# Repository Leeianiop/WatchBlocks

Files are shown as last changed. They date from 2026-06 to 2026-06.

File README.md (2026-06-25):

# WatchBlocks
The New Fashion is Customizable  
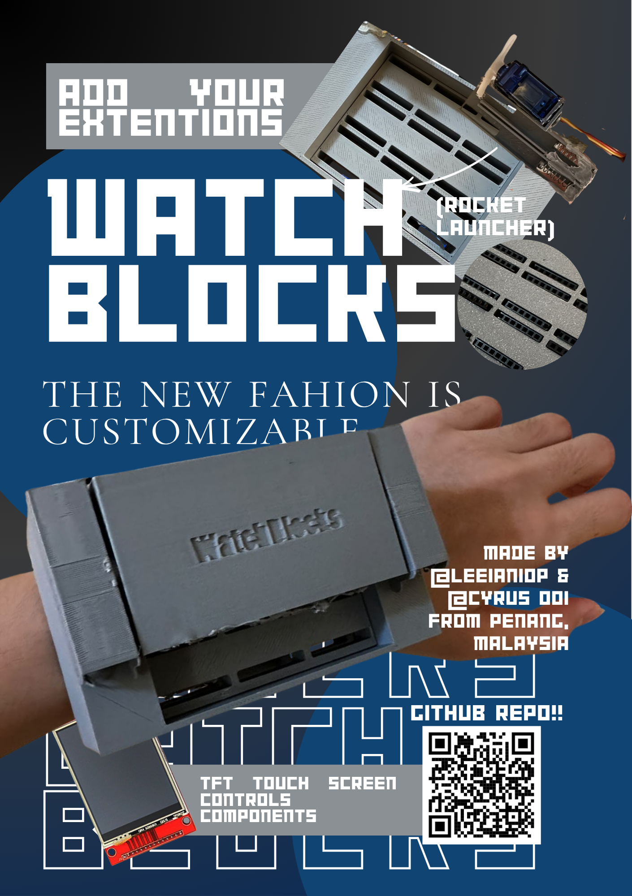
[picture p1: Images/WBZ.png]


## Inspired by the legendary "PhoneBlocks"  
A watch that can be added on extensions.

## How it started
This idea came to me when I saw the story of the PhoneBlocks Movement and how it eventually died out. I suppose an issue was also that nobody was willing to risk having their phones being blocks., and rather go with traditional "Big Brands"  
So, I lowered it down into a compact watch, well its more of a wrist bracelet thingymabob if you think about it. (WatchBlocks sounds cooler than Wrist-Bracelet-ThingymabobBlocks)  

## BOM
# WatchBlocks - Bill of Materials (BOM)

## Core Components

| Component | Description | Qty | Cost |
|---|---|---|---|
| ESP32S3 XIAO | Microcontroller | 1 | $13.73 |
| 1.8" TFT Touch Screen Display | UI Display | 1 | $2.57 |
| Perfboard Wires | Connect the circuit | 1 | $1.48 |
| Female Pin Header (1x40) | Solder to PCB | 1 | $0.20 |
| Male Pin Header (1x40) | Connect extensions to socket | 6 | $0.72 |
| Magnets (10 pcs) | Locking extensions and closures | 1 | $1.20 |
| DS3231 RTC Module | Track local time offline | 1 | $2.21 |

## Power System

| Component | Description | Qty | Cost |
|---|---|---|---|
| Lipo Battery 3.7v | Supply power | 1 | $1.03 |
| Velcro Strap | Wrist strap | 1 | $3.01 |
| Velcro Patch | Attach block to strap | 1 | $1.15 |

## Speaker Extension

| Component | Description | Qty | Cost |
|---|---|---|---|
| 4Ω Speaker | Audio output | 1 | $3.63 |

## Rocket Launcher 3000 Extension

| Component | Description | Qty | Cost |
|---|---|---|---|
| Servo Motor | Launch mechanism | 1 | $1.54 |
| Springs | Hold and launch rockets | 1 | $0.76 |

## PCB 4 layers

| Component | Description | Qty | Cost |
|---|---|---|---|
| Top PCB | Get Quote on JLCPCB | 1 | $7 |
| Bottom PCB | Get Quote on JLCPCB | 1 | $7 |

# Total Cost

**$47.23**

## Files
STL files include an extentions folder which are for the speaker extention and rocket launcher extentions.     
If you want to make your own extention which you definetly should (its the whole purpose of this project) modify (WatchBlocksTemplate)    
PCB file has 2 pcb inside for the top (left) and bottom layer (right).  PCB also has 4 layers, below are all of them separately   
PCB "+" Sign also indicates the way you should place the PCB, so make sure bot "+" of your PCB are facing the same direction
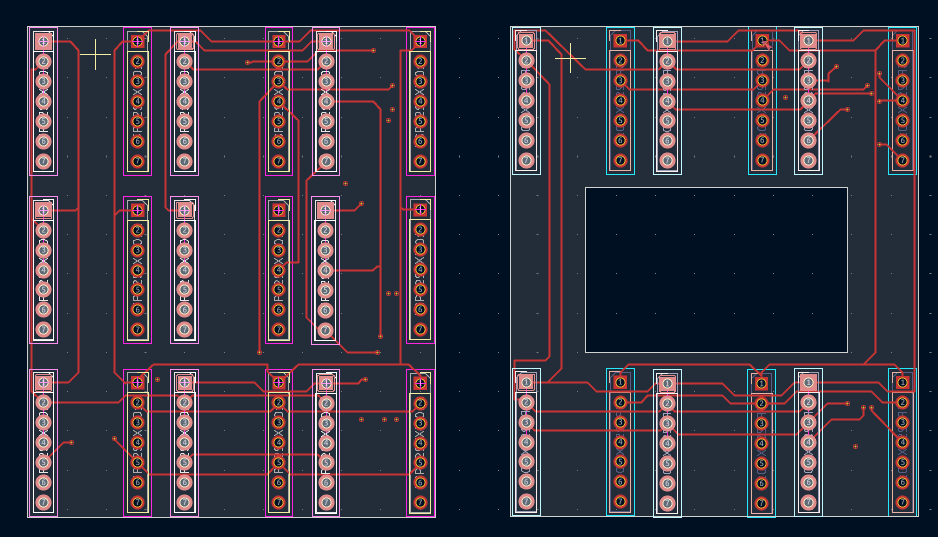
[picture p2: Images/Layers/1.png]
  
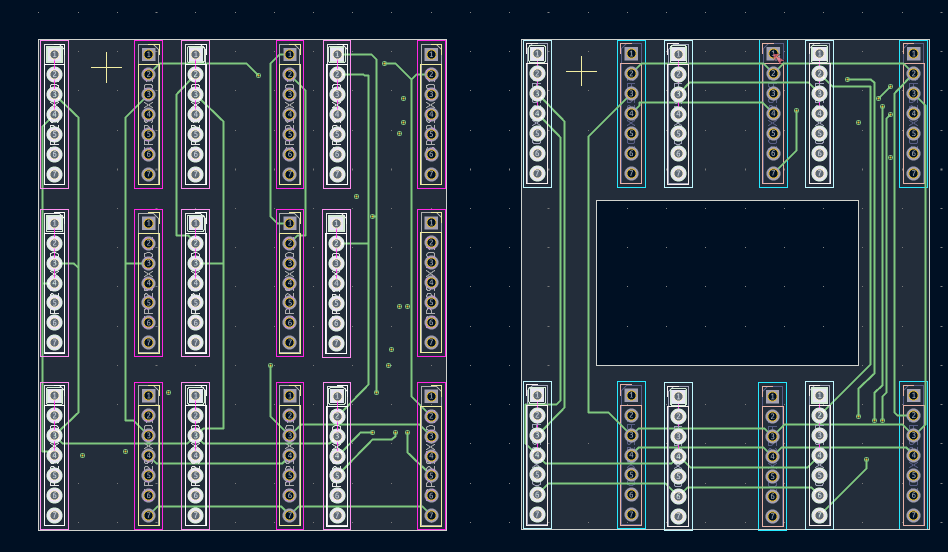
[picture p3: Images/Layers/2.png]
  
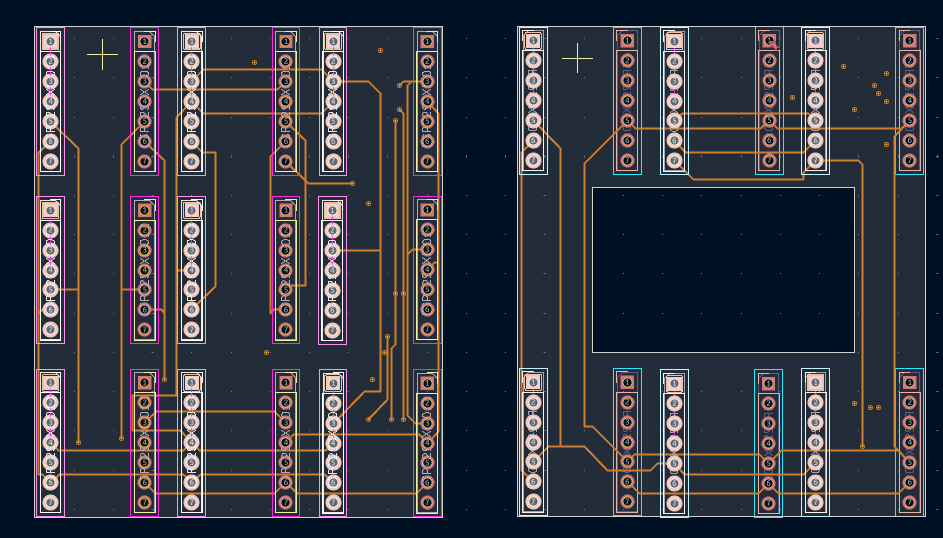
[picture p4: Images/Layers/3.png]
  
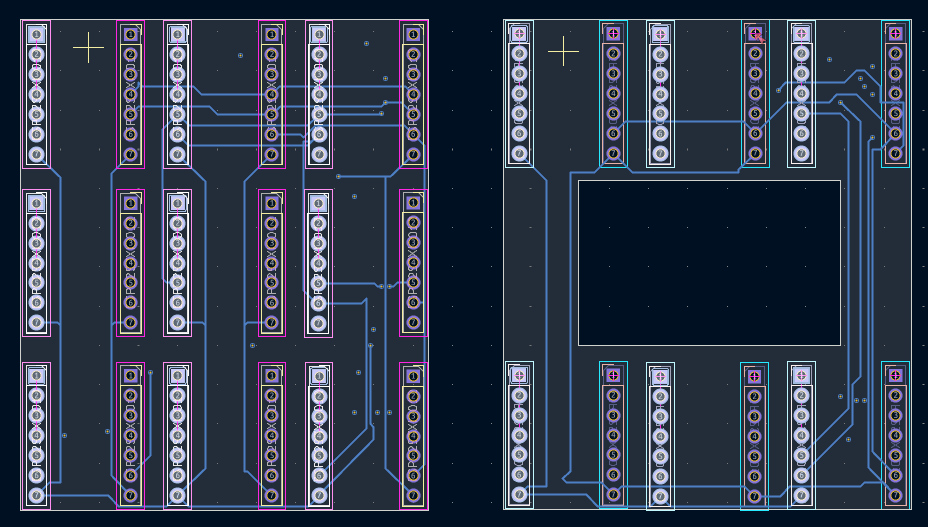
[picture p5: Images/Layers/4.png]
   
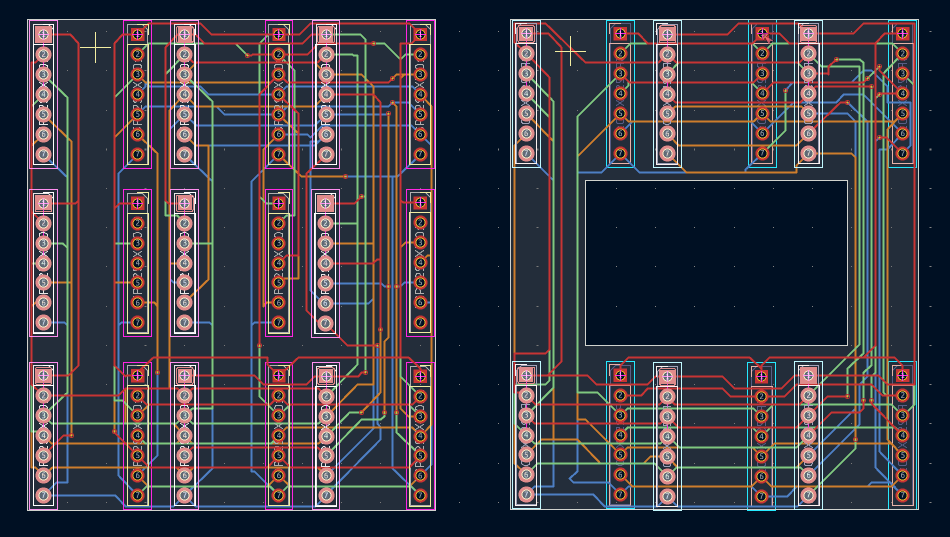
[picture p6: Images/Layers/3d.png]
  
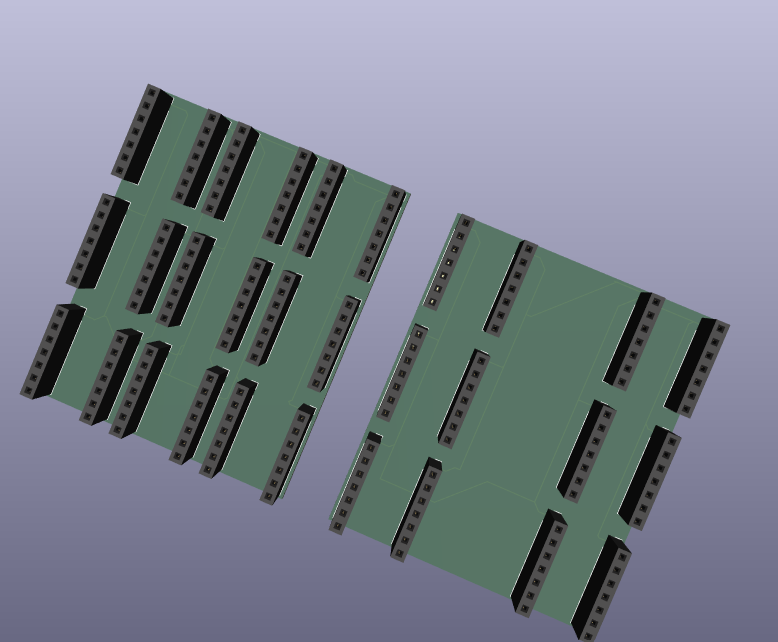
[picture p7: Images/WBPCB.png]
  
## Where everything goes  
### 1. Start by soldering the wires then sliding in the tft.  
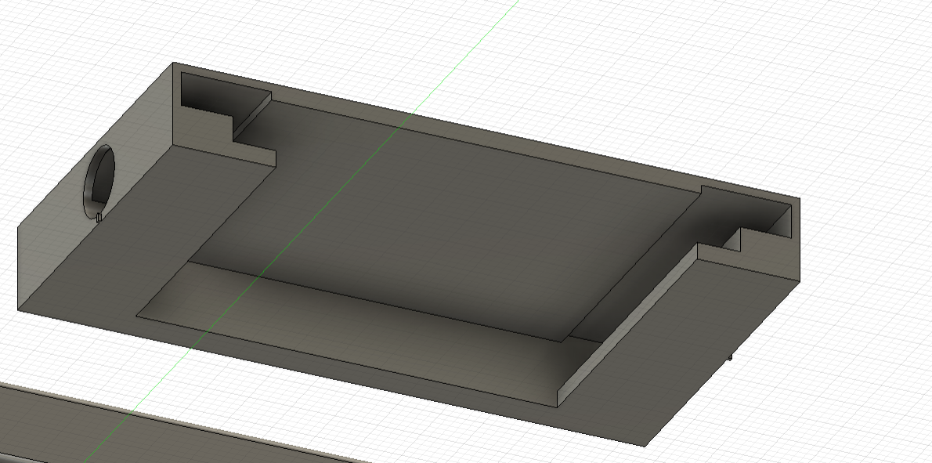
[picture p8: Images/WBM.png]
  
### 2. Close the lid & fit both the sliders in, remember to fit the wires of the tft through the hole and into the main case.
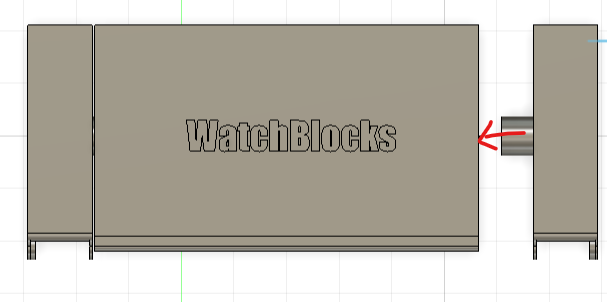
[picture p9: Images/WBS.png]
  
### 3. Align with Main Case and Hot glue them with the nuts and screws  
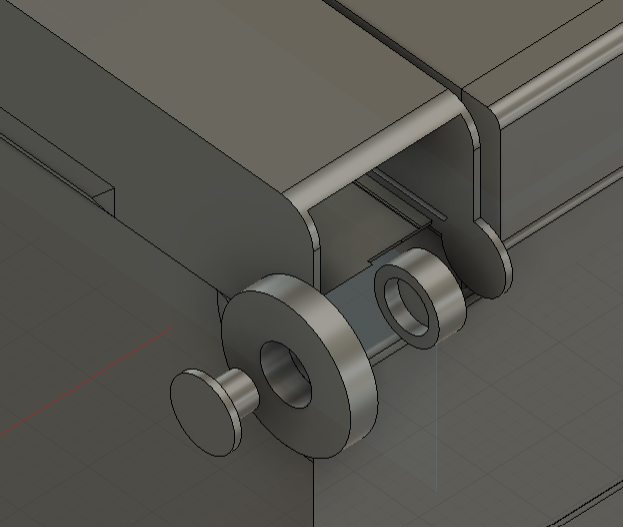
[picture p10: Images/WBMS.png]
  
### 4. IMPORTANT!! solder bottom pcb first (the one with 12 pin headers) Place xiao in (bottom to top), then use perfboard wire to connect them with XIAO, only then insert PCB in  
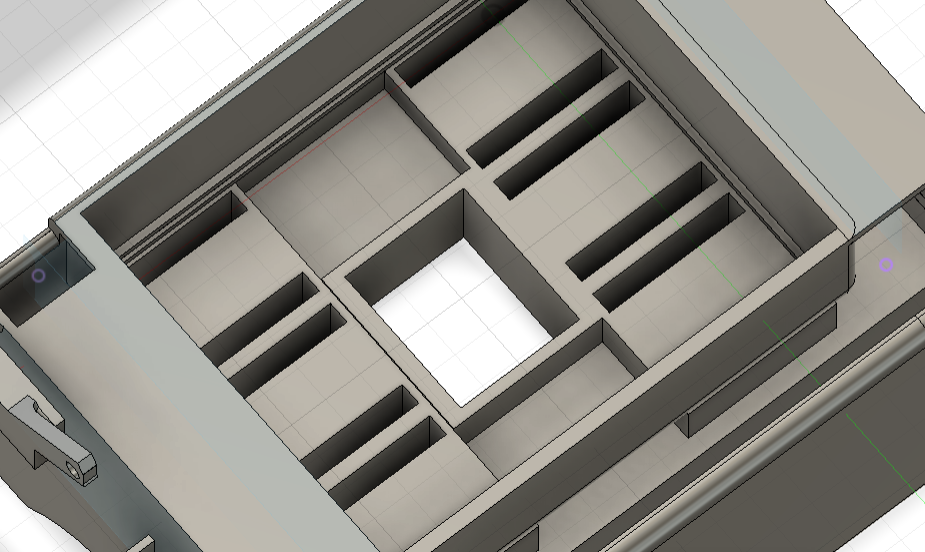
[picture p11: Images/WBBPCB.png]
  
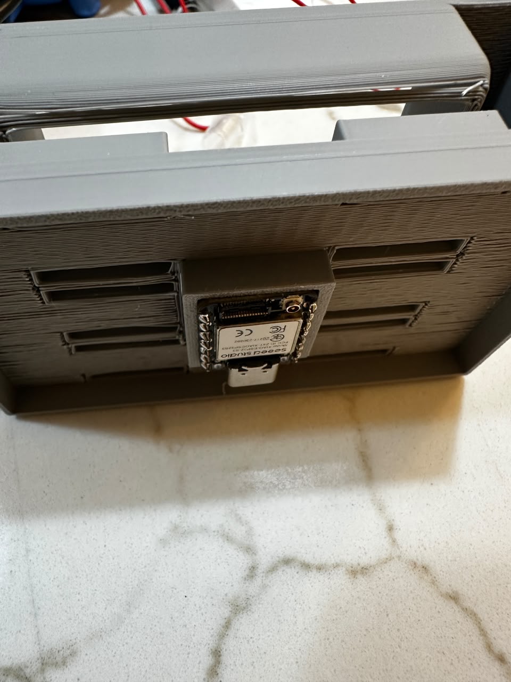
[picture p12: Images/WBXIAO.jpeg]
  
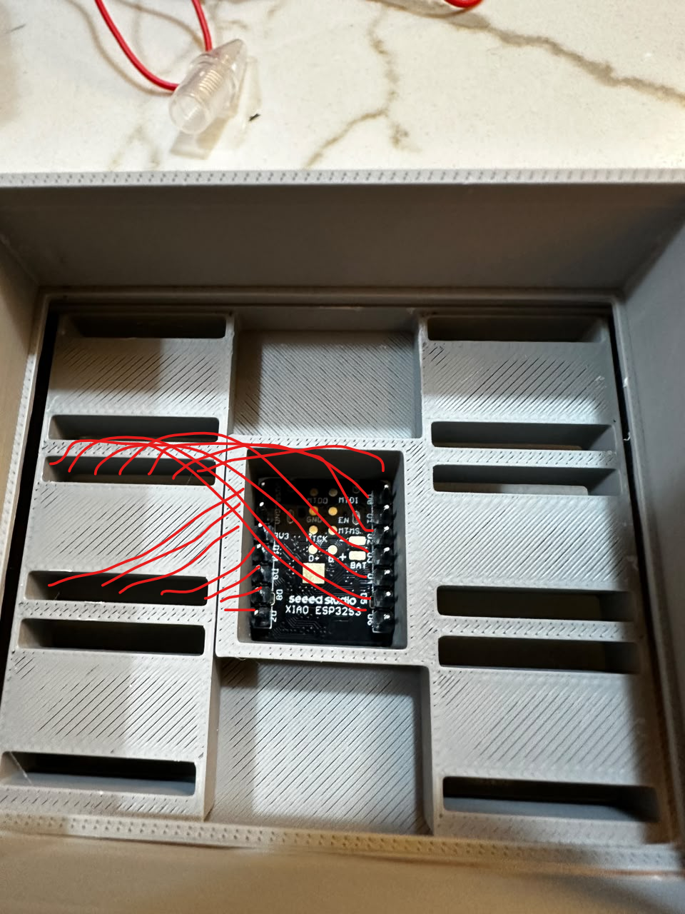
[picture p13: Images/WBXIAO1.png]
  
### 5. Now solder the to pcb with the XIAO and place it in, then put on the cover (WatchBlocksSocket)  
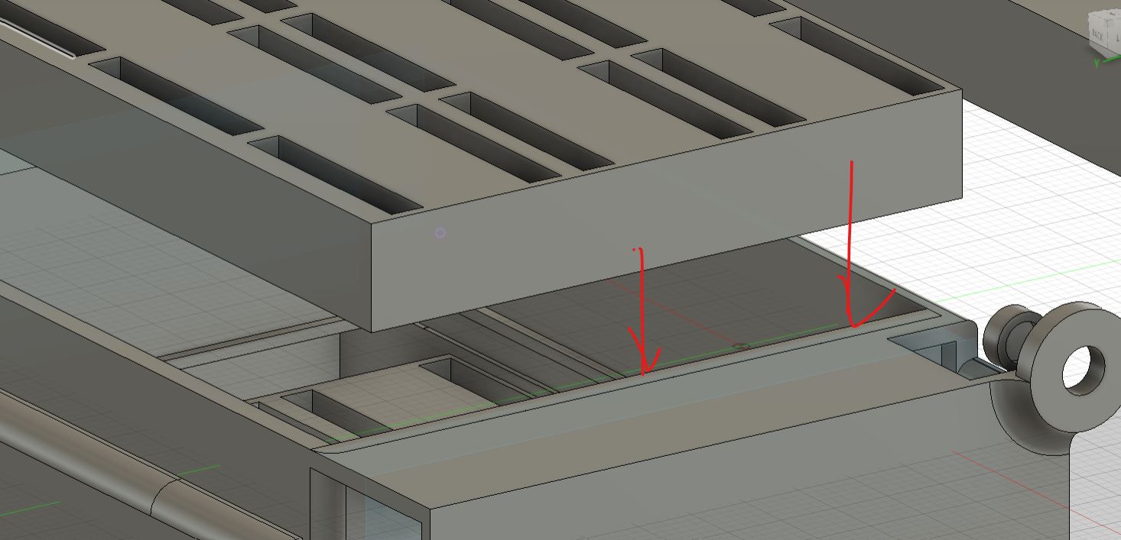
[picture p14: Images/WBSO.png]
   
### 6. Place Lipo battery in this cover, then connect with VBUS and GND to the pin headers
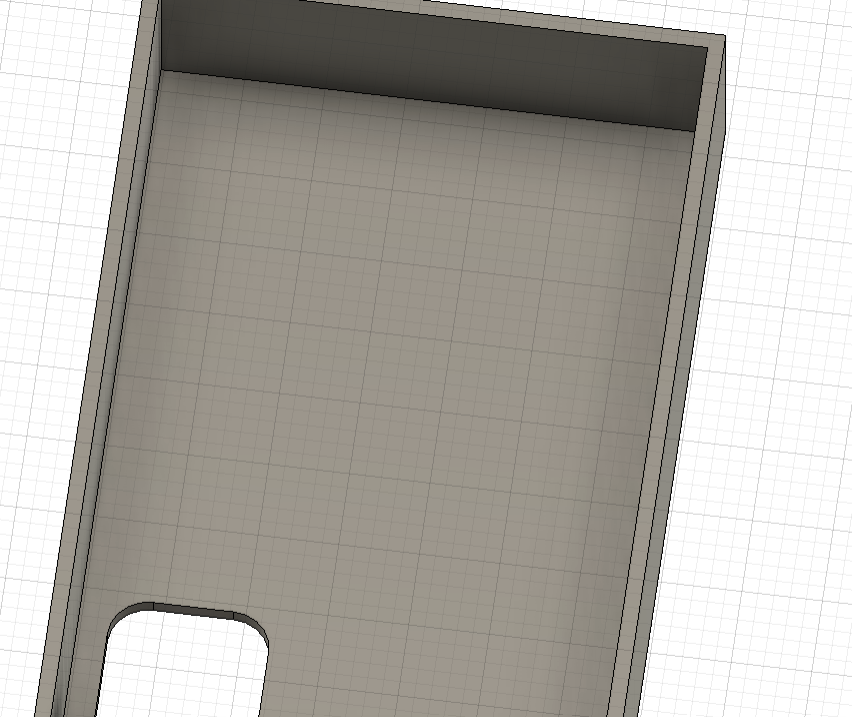
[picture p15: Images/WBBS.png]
  
### 7. Fit your RTC module in here and connect directly to the XIAO sharing the same I2C bus  
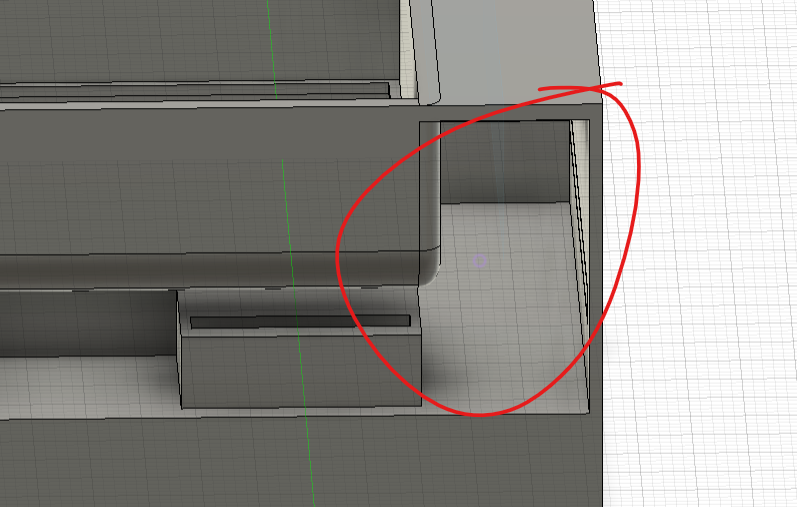
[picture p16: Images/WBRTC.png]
  
### 8. Close the MAIN Lid, and that's it, really simple !!  
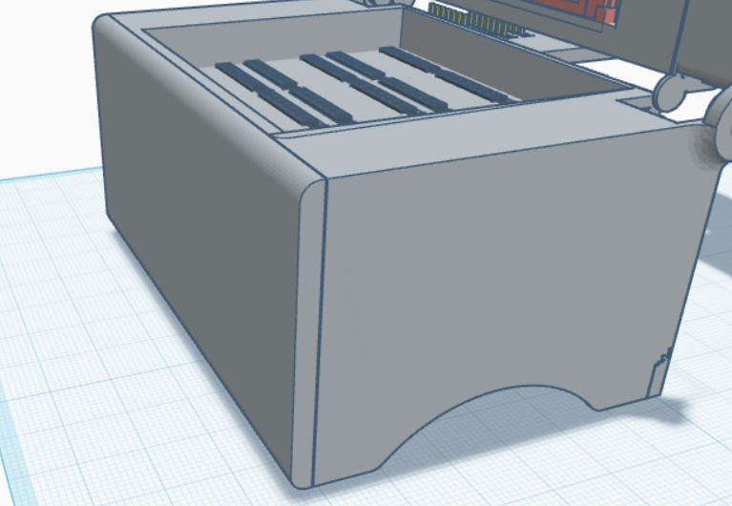
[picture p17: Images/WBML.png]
  
## Final assembly below (Including PCB):  
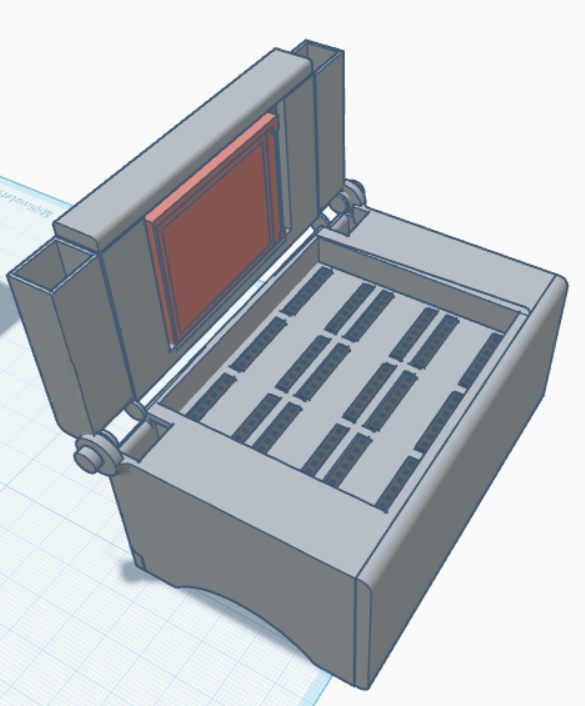
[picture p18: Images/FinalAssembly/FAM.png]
  
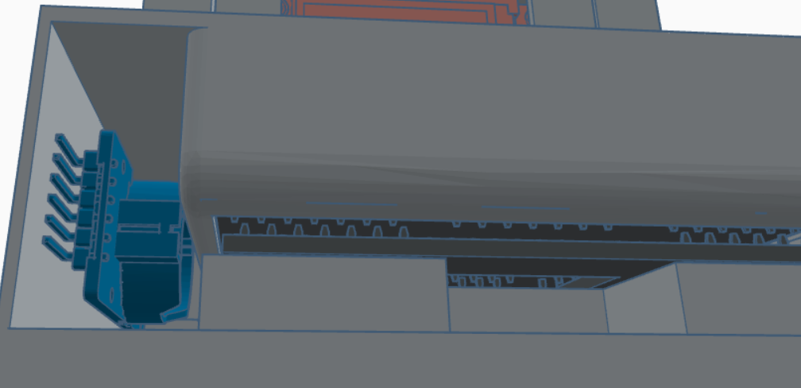
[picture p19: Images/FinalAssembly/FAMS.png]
  
# Battery Extention:  
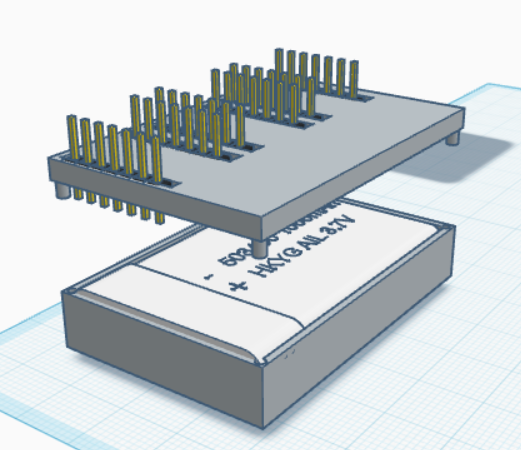
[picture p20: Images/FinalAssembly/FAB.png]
  
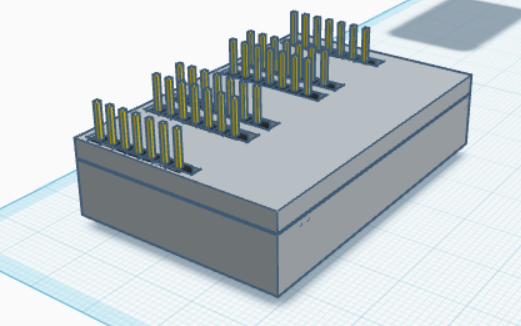
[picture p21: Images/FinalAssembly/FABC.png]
 

## Extentions
For the servo extension, get springs and hot glue them down, it's the only way to keep them locked in place,   
Screw on the hinge to the servo then mount the servo.  
Also install 4x1x7 pin headers at the bottom and connect with the servo according to the schematic  
### Final assembly below:  
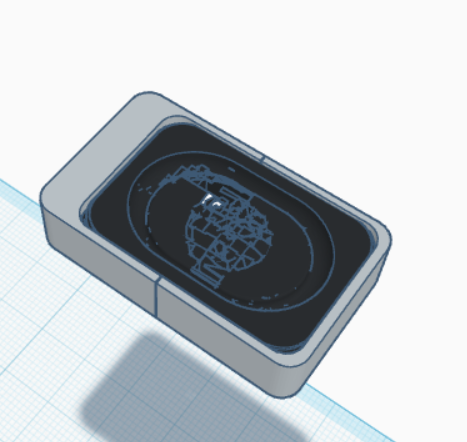
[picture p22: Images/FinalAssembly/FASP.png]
    
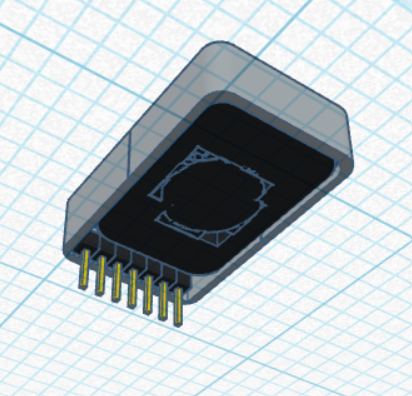
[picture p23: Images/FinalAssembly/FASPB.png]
   
For the speaker just slot it in and solder to pin headers according to the schematic. 
### Final Assembly below:  
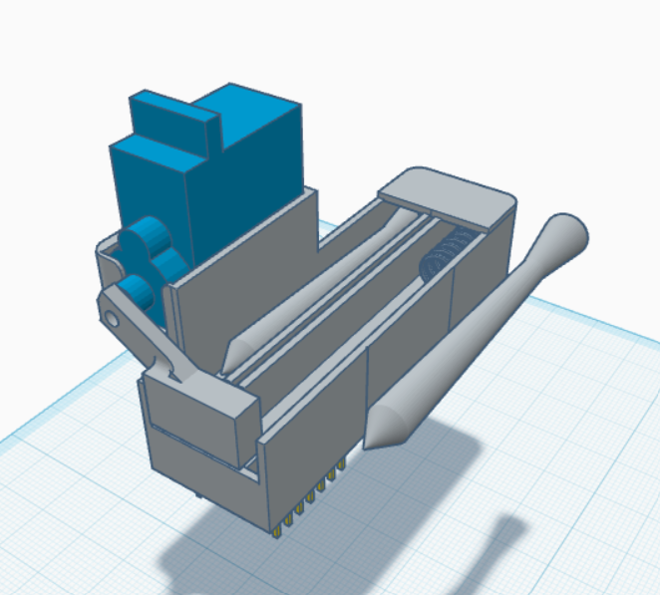
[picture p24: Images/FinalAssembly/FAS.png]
    
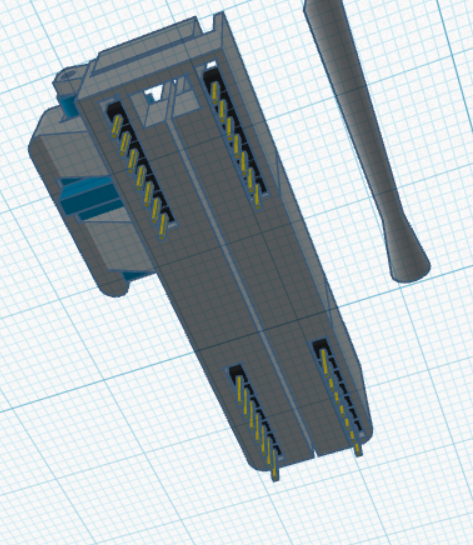
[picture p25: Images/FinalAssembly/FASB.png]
   
## Schematic
For those who think the schematic is hard to comprehend, it is just pin headers connected to their corresponding pin of the XIAO, so its like every extention is a XIAO itself. The components work by sharing the same i2c or spi bus also.  
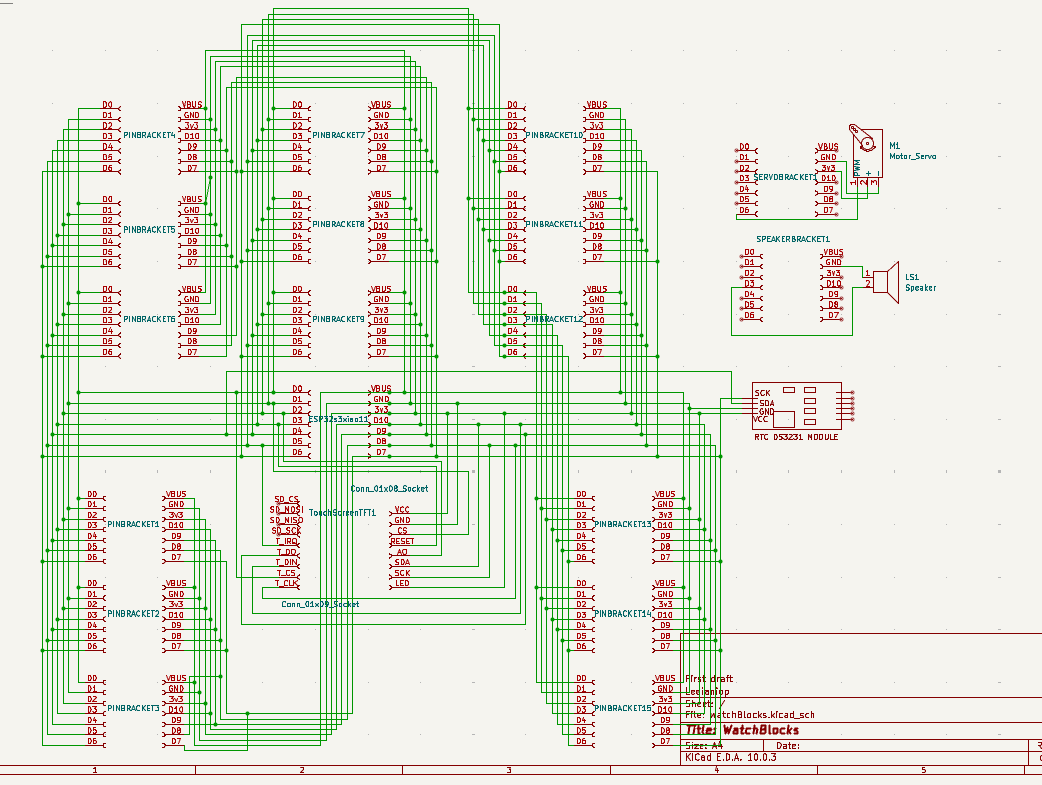
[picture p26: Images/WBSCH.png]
  

## Make Your Own Extension?
Just work on the (WatchBlocksTemplate) file but instead of female pin headers make the bottom male pin headers. Then update the code according to your components.

## Notes
Hope you like and enjoy this project as much as I do, 36 hours logged :)

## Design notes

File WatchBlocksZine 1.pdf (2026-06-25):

# ADD your extentions

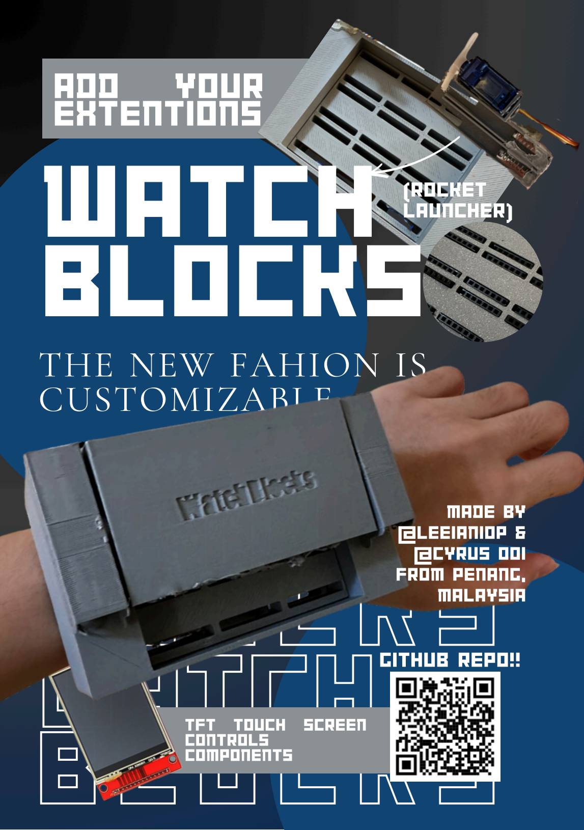
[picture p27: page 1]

# WATCH BB LL OO CC KK SS WATCH BB LL OO CC KK SS

# THE NEW FAHION IS CUSTOMIZABLE

(rocket
Launcher)

tft touch screen
controls
components

# WATCH BLOCKS

GITHUB REPO!!

Made by
@leeianiop &
@Cyrus OOI
from PENANG,
MALAYSIA

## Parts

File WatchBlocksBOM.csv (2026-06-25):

Components | Description | Link | Unit Price ($) | Quantity | Total ($)
ESP32S3 XIAO | Microcontroller | https://www.lazada.com.my/products/seeed-studio-xiao-esp32-c3c6s3-optional-mini-development-board-module-24ghz-wifible-50for-arduino-iot-intelligent-system-i4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 | $13.73 | 1 | $13.73
1.8Inch TFT Touch Screen display | UI display | https://shopee.com.my/product/299149454/21474104300?d_id=fa282&uls_trackid=55ul17kv02bl | $2.57 | 1 | $2.57
Perfboard wires | Connect the circuit | https://www.lazada.com.my//products/i3898574832-s22557322350.html?urlFlag=true | $1.48 | 1 | $1.48
Pin Header Female (1x40) | Solder to PCB | https://www.lazada.com.my//products/i4663837363-s26181719273.html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 | $0.20 | 1 | $0.20
Pin Header Male (1x40) | Connect Extentions to socket | https://www.lazada.com.my//products/i421963311-s614288662.html?urlFlag=true | $0.12 | 6 | $0.72
Magnets (10 pcs) | Locking in the Extentions and closers | https://www.lazada.com.my//products/i793744936-s1839704356.html?urlFlag=true | $1.20 | 1 | $1.20
DS3231 RTC module | Track local time offline | https://www.lazada.com.my//products/i131084606-s146041975.html?urlFlag=true&tradePath=%2CcartPriceDrop%2Ccart | $2.21 | 1 | $2.21
Lipo Battery 3.7v | Suply Power | https://www.lazada.com.my//products/i4813443032-s27233939882.html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 | $1.03 | 1 | $1.03
Velcro Patch | Tape Block onto Strap | https://www.lazada.com.my/products/pdp-i4130125160-s23389544188.html?c=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 | $1.15 | 1 | $1.15
Velcro Strap | Suply Power | https://www.lazada.com.my/products/pdp-i3184137208-s16130842727.html?c=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 | $3.01 | 1 | $3.01
PCB 4 Layers Top | The main PCB with sockets | JLCPCB Quote | $7.00 | 1 | $7.00
PCB 4 Layers Bottom | The bottom PCB with sockets | JLCPCB Quote | $7.00 | 1 | $7.00
EXTENTIONS
SPEAKER
4 ohm speaker | Playing Sound | https://www.lazada.com.my//products/i4151232045-s23547423704.html?urlFlag=true | $3.63 | 1 | $3.63
ROCKET LAUNCHER 3000
Servo Motor | Releasing the rockets | https://www.lazada.com.my/products/servo-motor-mg995-mg996r-55g-sg90-9g-mg90s-s3003-metal-plastic-gear-180-360-deg-degree-standard-micro-size-servo-motor-with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 | $1.54 | 1 | $1.54
Springs | Contain the rockets | https://www.lazada.com.my/products/pdp-i4206884428-s23838858926.html?c=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 | $0.76 | 1 | $0.76
 |  |  |  | TOTAL: | $47.23

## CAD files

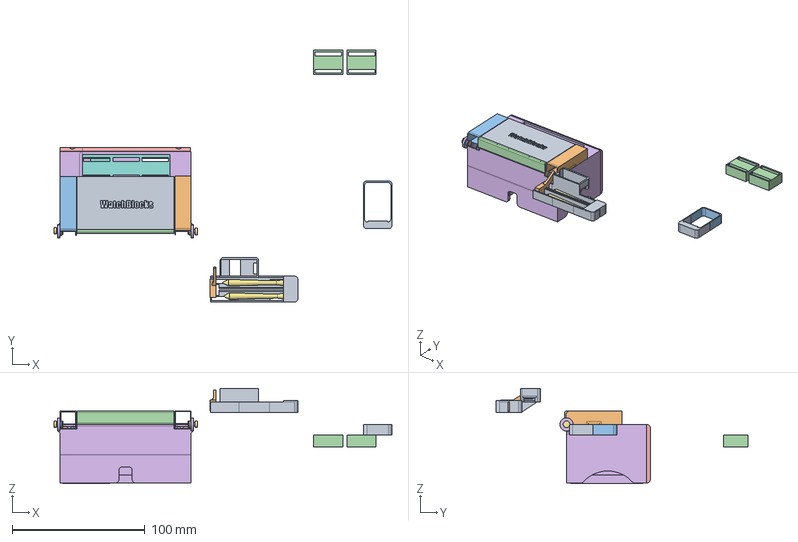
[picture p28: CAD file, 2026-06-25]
WatchBlocksAssembly.step
254.2 x 189.6 x 71.5 mm
MainCase
Left
Right
hj
jk
d
df
WatchBlocksAssembly
Top
Bottom
WatchBlocksAssembly (1)
WatchBlocksAssembly (2)
WatchBlocksAssembly (2) (1)
WatchBlocksAssembly (1) (1)
WatchBlocksAssembly (1) (2)
WatchBlocksAssembly (1) (3)
WatchBlocksAssembly (1) (1) (1)
WatchBlocksAssembly (1) (1) (1) (1)
WatchBlocksAssembly (1) (1) (1) (1) (1)
WatchBlocksAssembly (1) (1) (2)
WatchBlocksAssembly (2) (2)
WatchBlocksAssembly (1) (4)
h

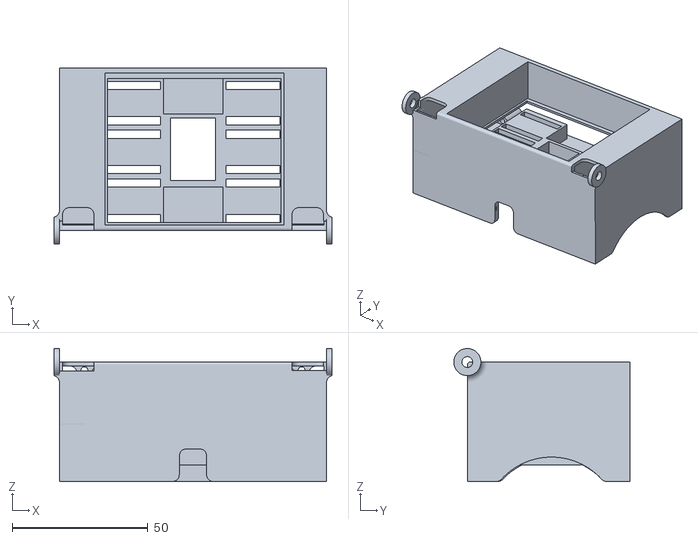
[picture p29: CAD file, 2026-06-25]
WatchBlocksCAD1/WatchBlocksMainCase.stl
102.4 x 65.0 x 49.0

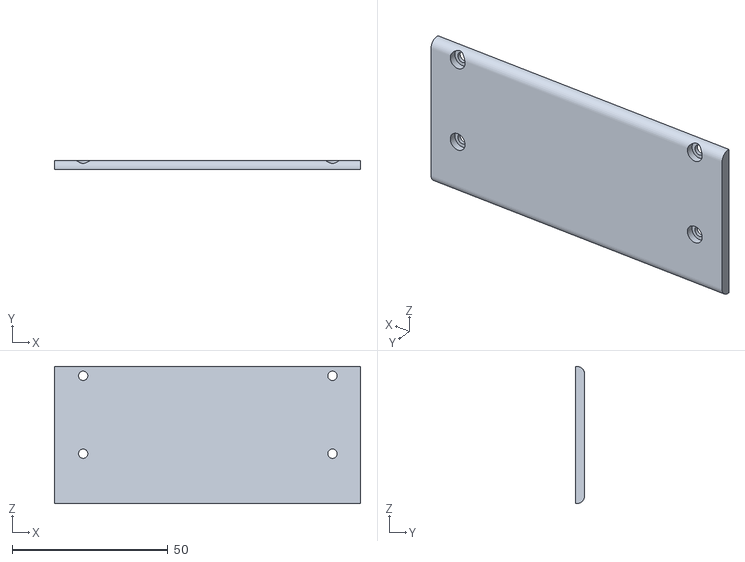
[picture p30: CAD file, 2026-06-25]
WatchBlocksCAD1/WatchBlocksMainClose.stl
98.2 x 3.00 x 44.0

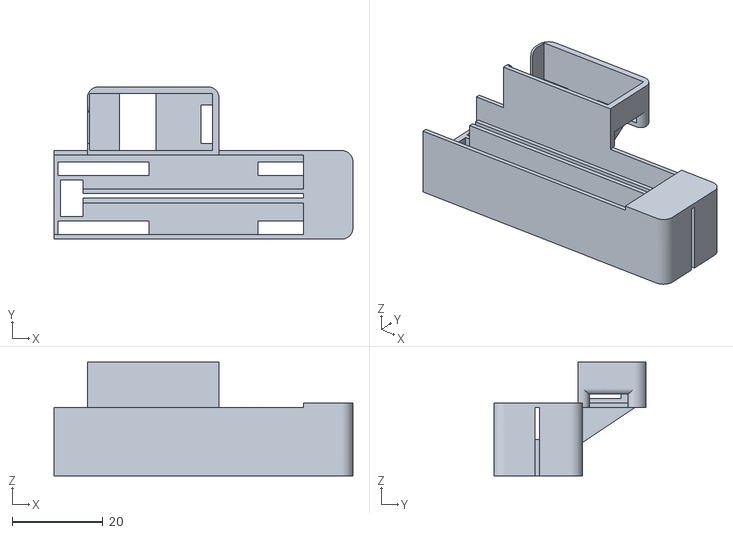
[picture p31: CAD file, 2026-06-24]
WatchBlocksCAD1/Extentions/WatchBlocksServo.stl
65.8 x 33.6 x 25.0

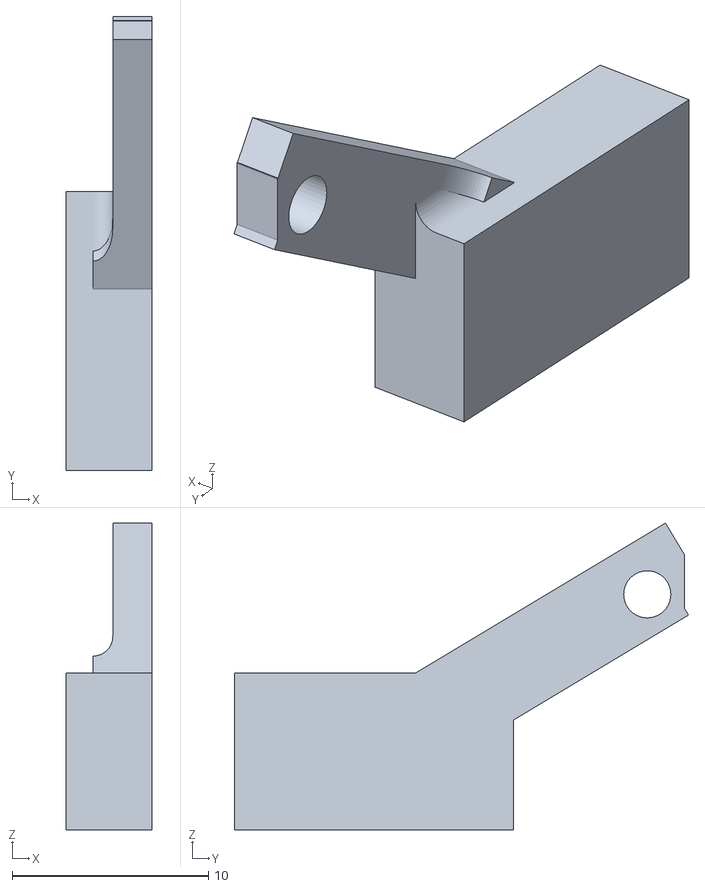
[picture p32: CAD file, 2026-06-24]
WatchBlocksCAD1/Extentions/WatchBlocksE_Servo_Hinge.stl.stl
4.38 x 23.1 x 15.6

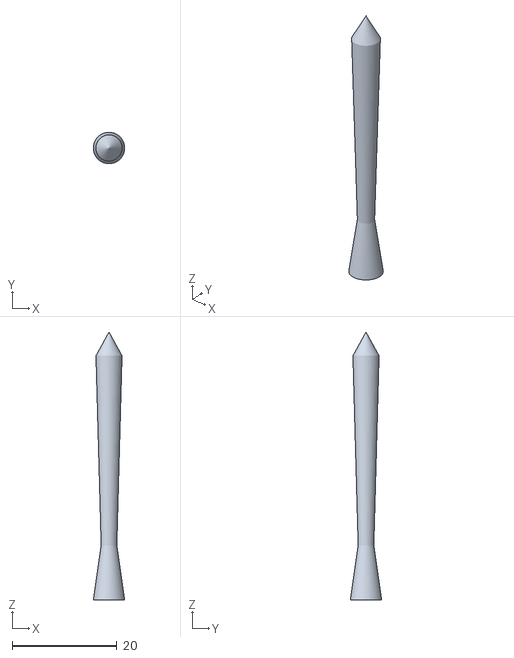
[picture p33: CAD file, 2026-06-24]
WatchBlocksCAD1/Extentions/WatchBlocksE_Servo_Rocket.stl.stl
5.99 x 6.00 x 51.2

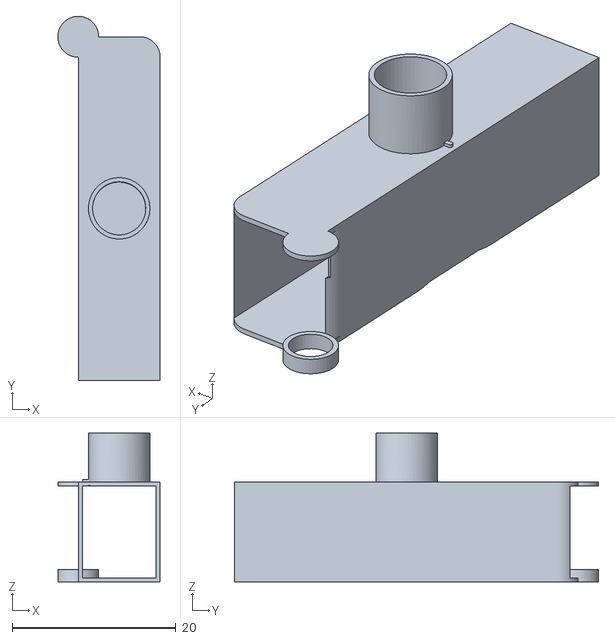
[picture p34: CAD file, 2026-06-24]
WatchBlocksCAD1/WatchBlocksRight.stl
12.5 x 44.5 x 18.2

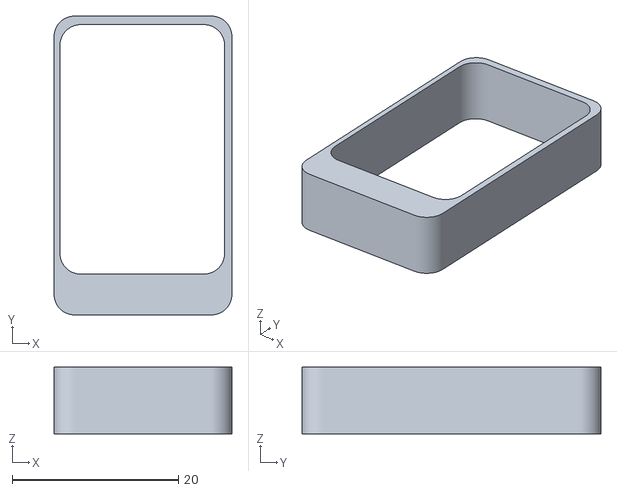
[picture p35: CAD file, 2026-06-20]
WatchBlocksCAD1/Extentions/WatchBlocksE_Speaker.stl
21.4 x 36.0 x 8.00

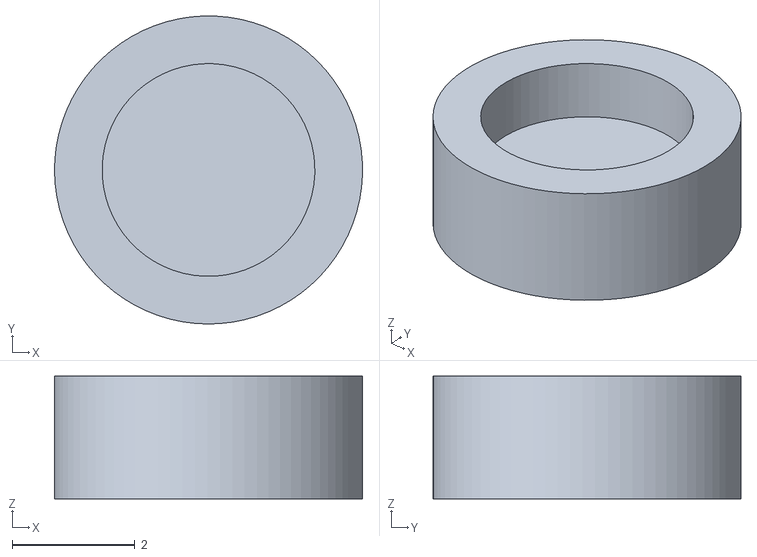
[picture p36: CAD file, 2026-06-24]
WatchBlocksCAD1/WatchBlocksCap.stl
5.01 x 5.01 x 2.00

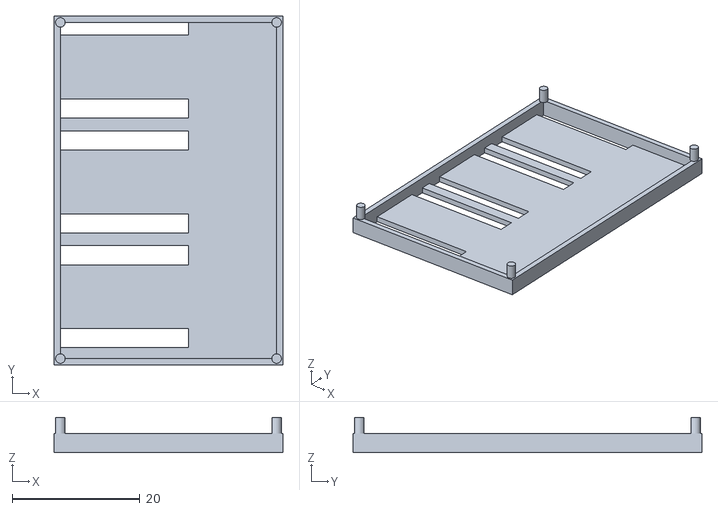
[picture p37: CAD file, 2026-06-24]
WatchBlocksCAD1/WatchBlocksBatteryCase.stl
35.9 x 54.7 x 5.50

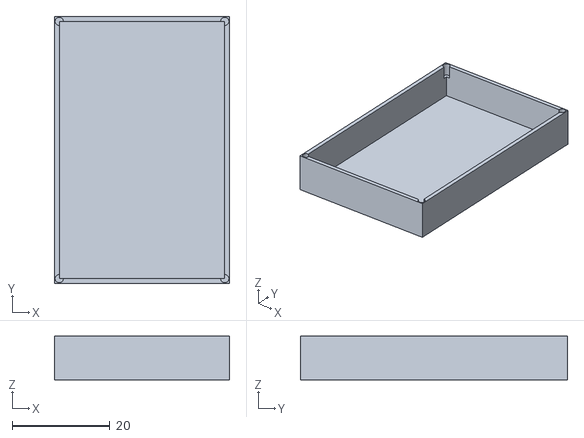
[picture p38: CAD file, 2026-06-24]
WatchBlocksCAD1/WatchBlocksBattery.stl
35.9 x 54.7 x 9.00

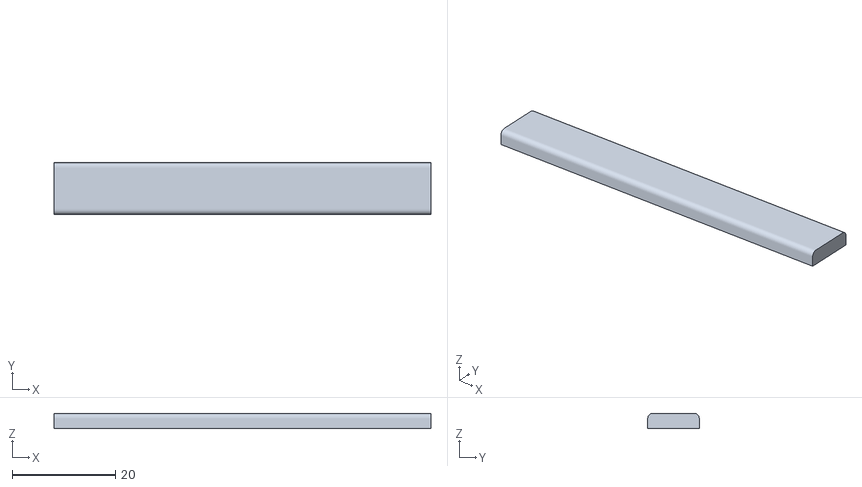
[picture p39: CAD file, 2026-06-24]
WatchBlocksCAD1/WatchBlocksTFTCover.stl
73.0 x 10.0 x 3.00

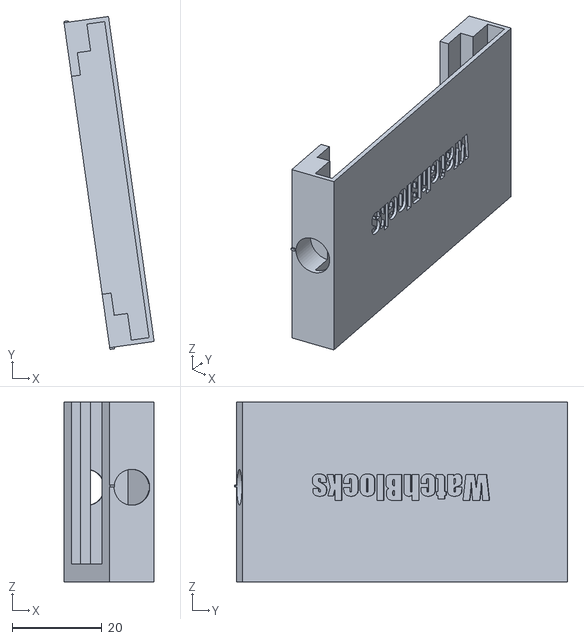
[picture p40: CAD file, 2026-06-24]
WatchBlocksCAD1/WatchBlocksTFTCase.stl
20.1 x 74.1 x 40.0

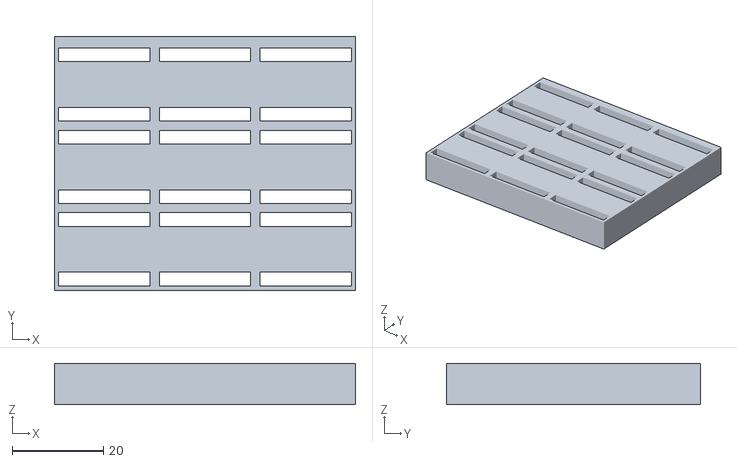
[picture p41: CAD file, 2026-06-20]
WatchBlocksCAD1/WatchBlocksSocket.stl
65.8 x 55.5 x 9.00

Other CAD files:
WatchBlocksCAD1/WatchBlocksLeft.stl
WatchBlocksCAD1/WatchBlocksTemplate.stl
WatchBlocksCAD1/WatchBlocksScrew.stl

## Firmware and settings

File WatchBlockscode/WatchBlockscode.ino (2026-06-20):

#include <SPI.h>
#include <Wire.h>
#include <RTClib.h>
#include <Adafruit_GFX.h>
#include <Adafruit_ST7735.h>
#include <XPT2046_Touchscreen.h>
#include <ESP32Servo.h>

// --- Pin Definitions ---
#define TFT_CS   D1
#define TFT_DC   D2  // 'A0' pin maps to Data/Command
#define TFT_RST  D3
#define TOUCH_CS  D0
#define TOUCH_IRQ D5 
#define SERVO_PIN D6

// RTC I2C Pins (From your code)
#define RTC_SDA   D4
#define RTC_SCL   D7

Adafruit_ST7735 tft(TFT_CS, TFT_DC, TFT_RST);
XPT2046_Touchscreen ts(TOUCH_CS, TOUCH_IRQ); 
Servo servo;
RTC_DS3231 rtc;

#define SCREEN_W 160
#define SCREEN_H 128

// --- Touchscreen Calibration Constants ---
#define TS_MINX 300
#define TS_MAXX 3800
#define TS_MINY 300
#define TS_MAXY 3800

// --- Modern 16-bit RGB565 Color Palette ---
#define COLOR_BG      0x18C3 
#define COLOR_CARD    0x2946 
#define COLOR_ACCENT  0x3CD9 
#define COLOR_TEXT    0xFFFF 
#define COLOR_MUTED   0x9CF3 
#define COLOR_ON      0x34EB 
#define COLOR_OFF     0xD224 
#define COLOR_SHADOW  0x0841 

bool servoOn = false;
unsigned long lastClockUpdate = 0;

enum Screen {
  HOME,
  CLOCK_VIEW,
  SETTINGS
};

Screen screen = HOME;

bool pressed(int px, int py, int x, int y, int w, int h) {
  return (px > x && px < x + w && py > y && py < y + h);
}

void drawBack() {
  tft.fillRoundRect(8, 8, 55, 24, 6, COLOR_SHADOW);
  tft.fillRoundRect(5, 5, 55, 24, 6, COLOR_CARD);
  tft.drawRoundRect(5, 5, 55, 24, 6, 0x4B55); 
  
  tft.setTextColor(COLOR_TEXT);
  tft.setTextSize(1);
  tft.setCursor(12, 13);
  tft.print("< BACK");
}

void drawIcon(int x, int y, uint16_t accentColor, const char* txt) {
  tft.fillRoundRect(x + 3, y + 3, 64, 52, 10, COLOR_SHADOW);
  tft.fillRoundRect(x, y, 64, 52, 10, COLOR_CARD);
  tft.fillRect(x + 10, y + 6, 44, 3, accentColor);
  
  tft.setTextSize(1);
  tft.setTextColor(COLOR_TEXT);
  int length = strlen(txt);
  int x_offset = (64 - (length * 6)) / 2; 
  
  tft.setCursor(x + x_offset, y + 26);
  tft.print(txt);
}

// Dynamically updates the real-time clock header on the Home Screen
void updateHomeClock() {
  if (!rtc.begin()) return;
  DateTime now = rtc.now();
  
  char buf[9];
  sprintf(buf, "%02d:%02d:%02d", now.hour(), now.minute(), now.second());
  
  // Clean text background overlay boundary box
  tft.fillRect(10, 8, 140, 16, COLOR_BG);
  
  tft.setTextColor(COLOR_TEXT);
  tft.setTextSize(2);
  tft.setCursor(32, 8);
  tft.print(buf);
}

void drawHome() {
  screen = HOME;
  tft.fillScreen(COLOR_BG);
  
  // Render the initial RTC Time header
  updateHomeClock();
  
  tft.drawFastHLine(10, 30, 140, 0x2946); 
  
  // App icons rearranged beautifully underneath the main clock
  drawIcon(12, 42, 0xF52A, "SERVO"); 
  drawIcon(84, 42, COLOR_ACCENT, "DETAILS");  
}

void drawClockView() {
  screen = CLOCK_VIEW;
  tft.fillScreen(COLOR_BG);
  drawBack();
  
  tft.setTextColor(COLOR_MUTED);
  tft.setTextSize(1);
  tft.setCursor(68, 13);
  tft.print("RTC STATUS");
}

void updateClockViewPage() {
  if (!rtc.begin()) return;
  DateTime now = rtc.now();

  char timeBuf[12];
  char dateBuf[12];
  sprintf(timeBuf, "%02d:%02d:%02d", now.hour(), now.minute(), now.second());
  sprintf(dateBuf, "%02d/%02d/%04d", now.month(), now.day(), now.year());
  
  tft.fillRoundRect(12, 48, 136, 60, 8, COLOR_CARD);
  tft.drawRoundRect(12, 48, 136, 60, 8, 0x10A2); 

  tft.setTextSize(2); 
  tft.setTextColor(0x07E0); // Electric digital green
  tft.setCursor(32, 58);
  tft.print(timeBuf);

  tft.setTextSize(1);
  tft.setTextColor(COLOR_MUTED);
  tft.setCursor(48, 88);
  tft.print(dateBuf);
}

void drawSettings() {
  screen = SETTINGS;
  tft.fillScreen(COLOR_BG);
  drawBack();
  
  tft.setTextColor(COLOR_TEXT);
  tft.setTextSize(2);
  tft.setCursor(15, 42);
  tft.print("Servo Control");

  tft.setTextColor(COLOR_MUTED);
  tft.setTextSize(1);
  tft.setCursor(15, 62);
  tft.print("Position Switch Panel");
  
  uint16_t switchColor = servoOn ? COLOR_ON : COLOR_OFF;
  tft.fillRoundRect(30, 82, 100, 32, 16, switchColor);
  
  if (servoOn) {
    tft.fillCircle(114, 98, 12, COLOR_TEXT); 
  } else {
    tft.fillCircle(46, 98, 12, COLOR_TEXT);  
  }
}

void moveServoFast(int target) {
  servo.write(target); 
}

void toggleServo() {
  servoOn = !servoOn;
  if (servoOn) {
    moveServoFast(90);
  } else {
    moveServoFast(0);
  }
  drawSettings();
}

void setup() {
  SPI.begin(D8, D9, D10); 
  Wire.begin(RTC_SDA, RTC_SCL); // Initializes your specified RTC I2C pins
  
  tft.initR(INITR_GREENTAB);
  tft.setRotation(3); 
  
  pinMode(TOUCH_CS, OUTPUT);
  digitalWrite(TOUCH_CS, HIGH);
  
  ts.begin(SPI); 
  ts.setRotation(3); 
  
  rtc.begin(); // Spins up the DS3231 timing hardware
  
  servo.attach(SERVO_PIN);
  servo.write(0);
  
  drawHome();
}

void loop() {
  // Handles non-blocking clock refresh cycles every second
  if (millis() - lastClockUpdate >= 1000) {
    lastClockUpdate = millis();
    if (screen == HOME) {
      updateHomeClock();
    } else if (screen == CLOCK_VIEW) {
      updateClockViewPage();
    }
  }

  if (ts.touched()) {
    TS_Point p = ts.getPoint();
    
    if (p.z > 200) {
      int x = map(p.x, TS_MINX, TS_MAXX, 0, SCREEN_W);
      int y = map(p.y, TS_MINY, TS_MAXY, 0, SCREEN_H);
      
      delay(75); 

      if (screen == HOME) {
        // Left Button (Servo Control)
        if (pressed(x, y, 2, 35, 74, 85)) {
          drawSettings();
        }
        // Right Button (Clock View Details)
        else if (pressed(x, y, 74, 35, 84, 85)) {
          drawClockView();
        }
      } 
      else {
        if (pressed(x, y, 0, 0, 75, 45)) {
          drawHome();
        }

        if (screen == SETTINGS) {
          if (pressed(x, y, 15, 72, 130, 50)) {
            toggleServo();
          }
        }
      }
    }
  }
  delay(10);
}

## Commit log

2026-06-23 Rename WatchBlocks BOM .csv to WatchBlocksBOM .csv
    [WatchBlocksBOM .csv]
2026-06-25 Rename WatchBlocksBOM 1.csv to WatchBlocksBOM.csv
    [WatchBlocksBOM.csv]
